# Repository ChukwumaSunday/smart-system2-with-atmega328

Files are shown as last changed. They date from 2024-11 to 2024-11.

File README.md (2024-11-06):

# smart-system2-with-atmega328
Pro-Tracking Solution Board is an ecosystem friendly onboard tracking technology and multi-functional development board based on ATMEGA328 microcontroller, designed to meet the requirements of embedded systems, vehicles/general tracking, providing a comprehensive set of features and peripherals on a single chip. 

PRO TRACKER SYSTEM
ABSTRACT:
The research is about creating a system for tracking vehicle, driver and products. Objective of the research is to design, develop and develop a GPS based
Tracking System in order to monitor and display location of vehicle on Google Maps and Other Dashboards. This system used ATMEGA328 as a microcontroller and it will be used as the main processing unit. Next, SIM7600E 4G LTE GSM/GPS module is used for network connectivity, routing the coordinate and connecting with the user.

INTRODUCTION
	Pro-Tracker Solution Board is an ecosystem friendly onboard tracking technology and multi-functional development board based on SIM7600E module that supports 4G network and  also support 2G/3G network communications, controlled by STM32 microcontroller, designed to meet the requirements of embedded systems, vehicles/general tracking, providing a comprehensive set of features and peripherals on a single board for DIY project kits. 
	The system is optimized for low power consumption and real-time processing, making it suitable for wide rand of applications.

AIM:
	To develop a multi-fuctional system that will solve the problem of location, driver and product tracking for both the military and civilians, perform driver and vehicle control, real time monitoring and ubiquitous in developing embedded systems/IoT technologies.
	To optimize the system for low power consumption and real-time processing, making it suitable for wide rand of applications.
	  To design a system that can be used in consumer products such as Vehicle Tracking System(VTS), Appliances Remote Controls, Motor Control Systems, IoT Projects, Medical devices, Gaming Console, Home Automation Systems and more.
Achievement: 
	Done with the schematic designs, board layout and ready for PCB fabrication.
Result: 
	No test carried out yet on the system as it’s still at design stage
Status of the project: 
	First stage which is PCB development is done. Therefore, the project is 40% near completion.
Conclusion:
	 All hands are on desk to ensure the project is completed as soon as possible if all the necessary system requirements are made available.

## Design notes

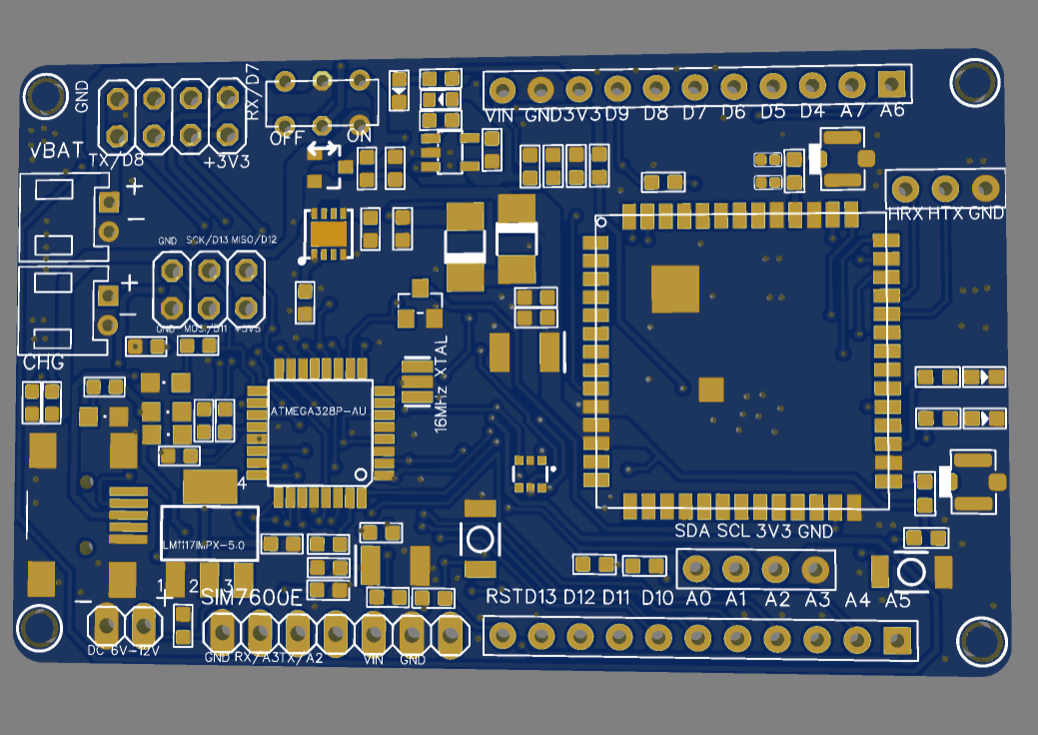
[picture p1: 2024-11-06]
Pro-Tracker(A9 ATmega328P-AU)/Front_Screenshot.png

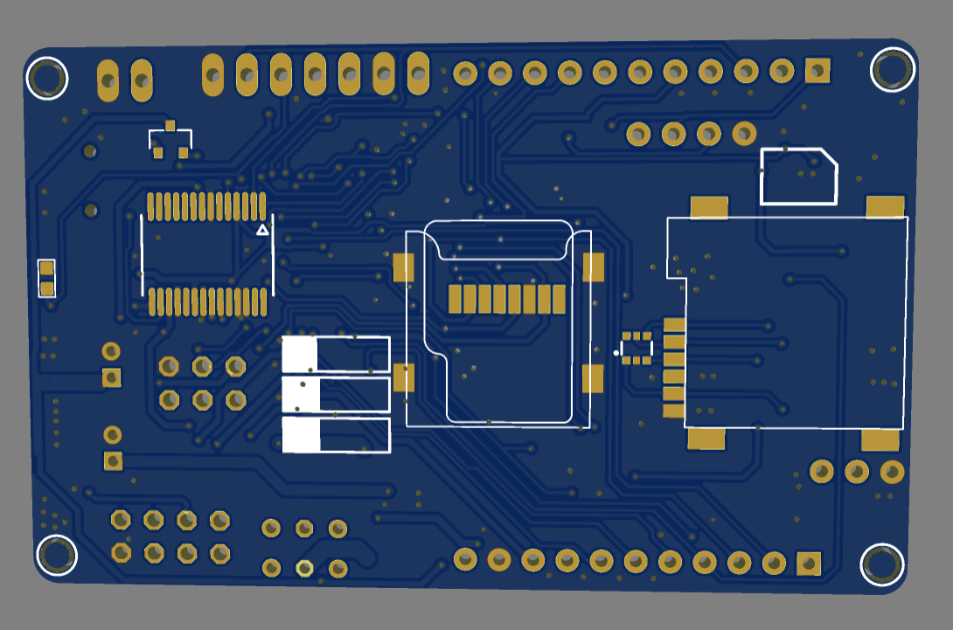
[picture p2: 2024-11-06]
Pro-Tracker(A9 ATmega328P-AU)/Back_Screenshot.png

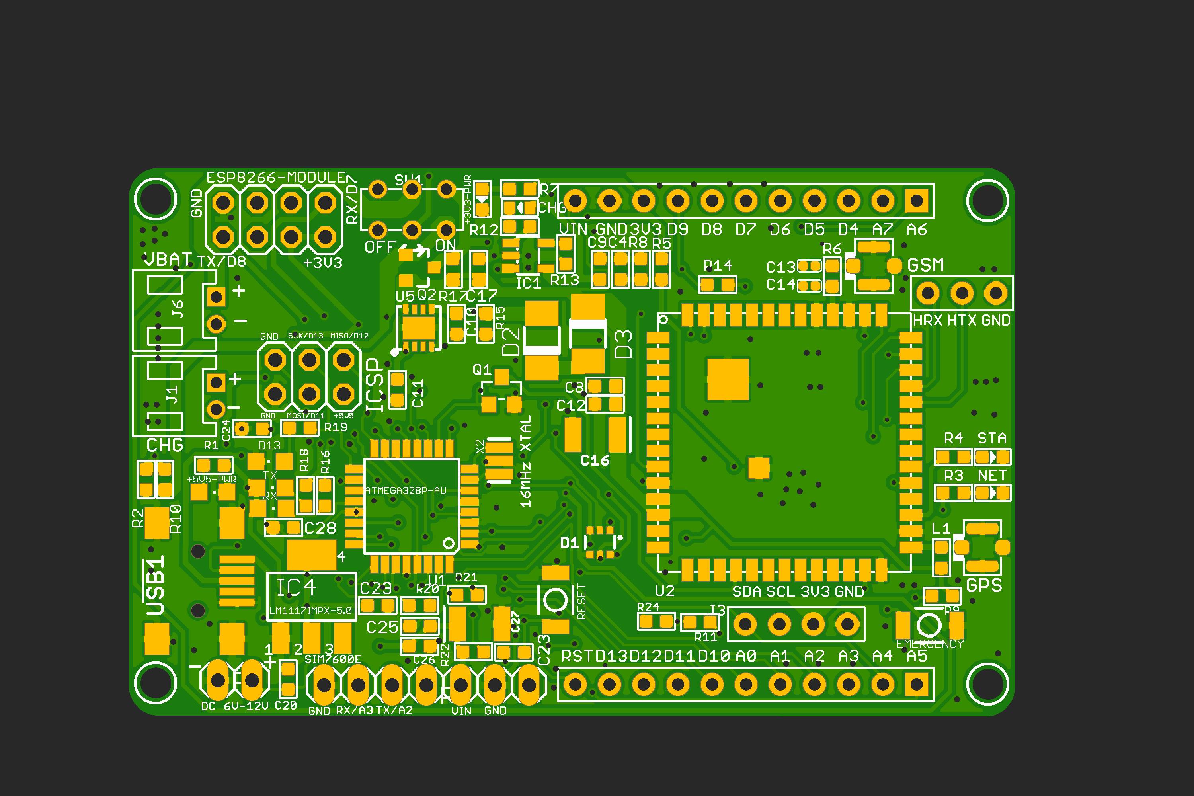
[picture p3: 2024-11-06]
Pro-Tracker(A9 ATmega328P-AU)/proto_tracks11_Top.png

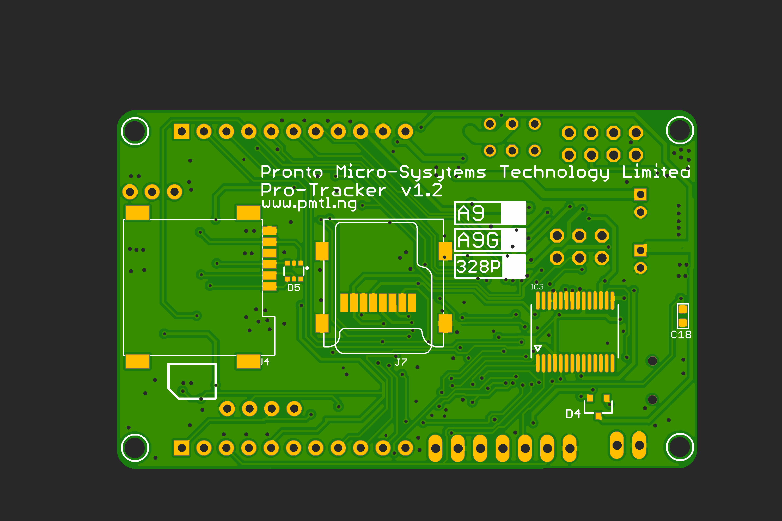
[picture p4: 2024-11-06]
Pro-Tracker(A9 ATmega328P-AU)/proto_tracks11_Bottom.png

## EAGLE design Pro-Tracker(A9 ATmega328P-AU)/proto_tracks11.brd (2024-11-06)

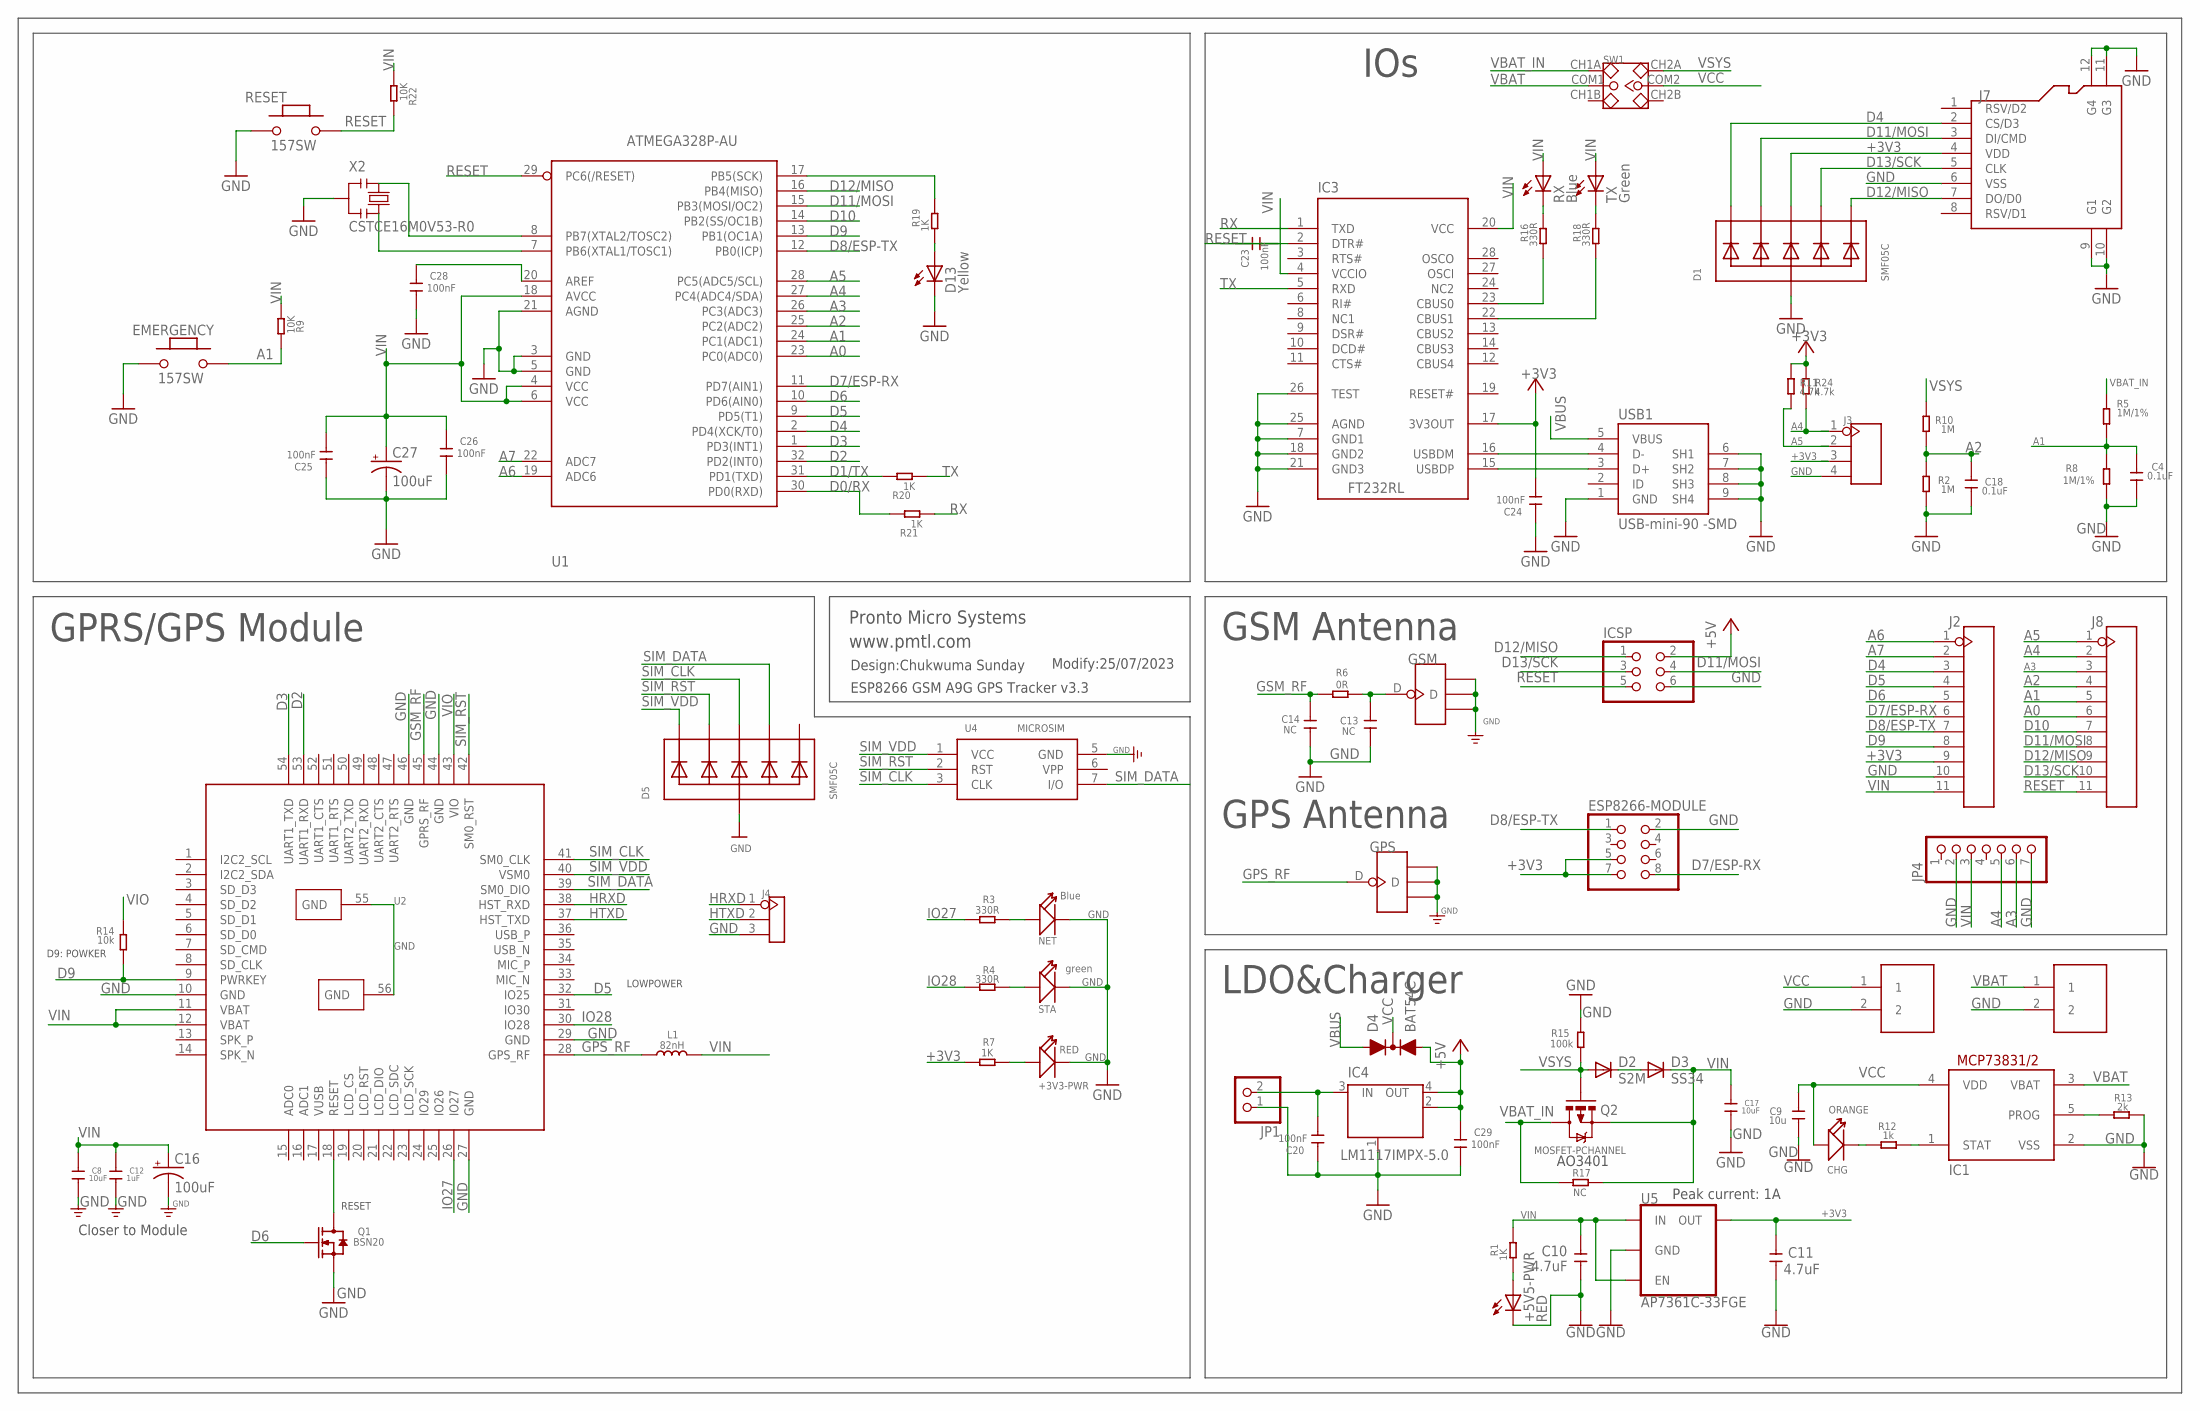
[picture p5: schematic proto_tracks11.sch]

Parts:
+3V3-PWR: RED; LED-0603
+5V5-PWR: RED; OPTO_CHIPLED_0805
C4, C18: 0.1uF; C0603
C8, C17: 10uF; C0603
C9: 10u; C0603
C10, C11: 4.7uF; C0603
C12: 1uF; C0603
C13, C14: NC; C0402
C16, C27: 100uF; EIA3528
C20, C23, C24, C25, C26, C28, C29: 100nF; C0603
CHG: ORANGE; D0603
D1, D5: SMF05C; SOT363
D2: S2M; DO-214AC
D3: SS34; DO-214AC
D4: BAT54C; SOT23-R
D13: Yellow; OPTO_CHIPLED_0805
EMERGENCY: 157SW; SWITCHES_SMD_157SW
ESP8266-MODULE: PINHD-2X4; 2X04
GPS: ANTENNA-U-FL; 4P-U-FL
GSM: ANTENNA-U-FL; 4P-U-FL
IC1: MCP73831/OT; SOT23-5L
IC3: FT232RL; INTEGRATEDCIRCUITS_SSOP28
IC4: LM1117IMPX-5.0; INTEGRATEDCIRCUITS_LINEAR_SOT223
ICSP: PINHD-2X3; 2X03
J1, J6: PH2.0-2P-90-DIP
J2, J8: HEADER-11P-2.54; 11P-2.54
J3: HEADER-4P-60/35MILROUND; 4P-65/35ROUND
J4: HEADER-3P-2.54; 3P-2.54
J7: HOLDER-MICROSD-8P; 8P-SMD
JP1: PINHD-1X2; 1X02
JP4: PINHD-1X7; 1X07
L1: 82nH; L0603
NET: Blue; LED-0603
Q1: BSN20; SOT23@1
Q2: MOSFET-PCHANNEL; SOT23-3
R1, R7, R19, R20, R21: 1K; R0603
R2, R10: 1M; R0603
R3, R4, R16, R18: 330R; R0603
R5, R8: 1M/1%; R0603
R6: 0R; R0603
R9, R22: 10K; R0603
R11, R24: 4.7k; R0603
R12: 1k; R0603
R13: 2k; R0603
R14: 10k; R0603
R15: 100k; R0603
R17: NC; R0603
RESET: 157SW; SWITCHES_SMD_157SW
RX: Blue; OPTO_CHIPLED_0805
STA: green; LED-0603
SW1: SWITCH-2CH-6P; 6P-2CH-2.54-7.6X3.0
TX: Green; OPTO_CHIPLED_0805
U1: ATMEGA328P-AU; ARDUINO-UCS&SOCS_TQFP32-08
U2: A9G
U4: MICROSIM
U5: AP7361C-33FGE; 8-UDFN
USB1: USB-mini-90 -SMD; CONNETTORI_USB-MINI-B_2
X2: CSTCE16M0V53-R0; CRISTALLI_RESONATOR

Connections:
+3V3: C11.2, C24.2, D1.4 (C3), ESP8266-MODULE.5, ESP8266-MODULE.7, IC3.17 (3V3OUT), J2.9, J3.3, J7.4 (VDD), R7.1, R11.2, R24.2, U5.1 (OUT)
+5V: C29.1, D4.2 (A2), IC4.2 (OUT), IC4.4 (OUT), ICSP.2
A0: J8.6, U1.23 (PC0(ADC0))
A1: C4.1, EMERGENCY.2, J8.5, R5.1, R8.2, R9.2, U1.24 (PC1(ADC1))
A2: C18.1, J8.4, R2.2, R10.1, U1.25 (PC2(ADC2))
A3: J8.3, JP4.6, U1.26 (PC3(ADC3))
A4: J3.1, J8.2, JP4.5, R24.1, U1.27 (PC4(ADC4/SDA))
A5: J3.2, J8.1, R11.1, U1.28 (PC5(ADC5/SCL))
A6: J2.1, U1.19 (ADC6)
A7: J2.2, U1.22 (ADC7)
D0/RX: R21.2, U1.30 (PD0(RXD))
D1/TX: R20.2, U1.31 (PD1(TXD))
D2: U1.32 (PD2(INT0)), U2.53 (UART1_RXD)
D3: U1.1 (PD3(INT1)), U2.54 (UART1_TXD)
D4: D1.1 (C1), J2.3, J7.2 (CS/D3), U1.2 (PD4(XCK/T0))
D5: J2.4, U1.9 (PD5(T1)), U2.32 (IO25)
D6: J2.5, Q1.1 (G), U1.10 (PD6(AIN0))
D7/ESP-RX: ESP8266-MODULE.8, J2.6, U1.11 (PD7(AIN1))
D8/ESP-TX: ESP8266-MODULE.1, J2.7, U1.12 (PB0(ICP))
D9: J2.8, R14.1, U1.13 (PB1(OC1A)), U2.9 (PWRKEY)
D10: J8.7, U1.14 (PB2(SS/OC1B))
D11/MOSI: D1.3 (C2), ICSP.4, J7.3 (DI/CMD), J8.8, U1.15 (PB3(MOSI/OC2))
D12/MISO: D1.6 (C5), ICSP.1, J7.7 (DO/D0), J8.9, U1.16 (PB4(MISO))
D13/SCK: D1.5 (C4), ICSP.3, J7.5 (CLK), J8.10, R19.2, U1.17 (PB5(SCK))
GND: +3V3-PWR.-, +5V5-PWR.C, C4.2, C8.1, C9.1, C10.1, C11.1, C12.1, C13.1, C14.1, C16.C (-), C17.1, C18.2, C20.1, C24.1, C25.1, C26.2, C27.C (-), C28.2, C29.2, D1.2 (A), D5.2 (A), D13.C, EMERGENCY.1, ESP8266-MODULE.2, GPS.GND1, GPS.GND2, GPS.GND3, GSM.GND1, GSM.GND2, GSM.GND3, IC1.2 (VSS), IC3.7 (GND1), IC3.18 (GND2), IC3.21 (GND3), IC3.25 (AGND), IC3.26 (TEST), IC4.1 (GND/ADJ), ICSP.6, J1.2, J2.10, J3.4, J4.3, J6.2, J7.6 (VSS), J7.9 (G1), J7.10 (G2), J7.11 (G3), J7.12 (G4), JP1.1, JP4.2, JP4.7, NET.-, Q1.2 (S), R2.1, R8.1, R13.2, R15.2, RESET.1, STA.-, U1.3 (GND), U1.5 (GND), U1.21 (AGND), U2.10 (GND), U2.27 (GND), U2.29 (GND), U2.44 (GND), U2.46 (GND), U2.55 (GND), U2.56 (GND), U4.5 (GND), U5.4 (GND), U5.EP (GND), USB1.1 (GND), USB1.6 (SH1), USB1.7 (SH2), USB1.8 (SH3), USB1.9 (SH4), X2.2
GPS_RF: GPS.D, L1.1, U2.28 (GPS_RF)
GSM_RF: C14.2, R6.1, U2.45 (GPRS_RF)
HRXD: J4.1, U2.38 (HST_RXD)
HTXD: J4.2, U2.37 (HST_TXD)
IO27: R3.1, U2.26 (IO27)
IO28: R4.1, U2.30 (IO28)
unnamed: R4.2, STA.+
unnamed: D2.C, D3.A
unnamed: +3V3-PWR.+, R7.2
unnamed: C28.1, U1.20 (AREF)
unnamed: +5V5-PWR.A, R1.1
unnamed: C20.2, IC4.3 (IN), JP1.2
unnamed: NET.+, R3.2
unnamed: Q1.3 (D), U2.18 (RESET)
unnamed: C23.2, IC3.2 (DTR#)
unnamed: R16.2, RX.C
unnamed: R18.2, TX.C
unnamed: IC3.23 (CBUS0), R16.1
unnamed: IC3.22 (CBUS1), R18.1
unnamed: IC3.15 (USBDP), USB1.3 (D+)
unnamed: IC3.16 (USBDM), USB1.4 (D-)
unnamed: D13.A, R19.1
unnamed: CHG.-, R12.1
unnamed: IC1.1 (STAT), R12.2
unnamed: IC1.5 (PROG), R13.1
unnamed: U1.7 (PB6(XTAL1/TOSC1)), X2.3
unnamed: U1.8 (PB7(XTAL2/TOSC2)), X2.1
unnamed: C13.2, GSM.D, R6.2
RESET: C23.1, ICSP.5, J8.11, R22.2, RESET.2, U1.29 (PC6(/RESET))
RX: IC3.1 (TXD), R21.1
SIM_CLK: D5.4 (C3), U2.41 (SM0_CLK), U4.3 (CLK)
SIM_DATA: D5.5 (C4), U2.39 (SM0_DIO), U4.7 (I/O)
SIM_RST: D5.3 (C2), U2.42 (SM0_RST), U4.2 (RST)
SIM_VDD: D5.1 (C1), U2.40 (VSM0), U4.1 (VCC)
TX: IC3.5 (RXD), R20.1
VBAT: IC1.3 (VBAT), J6.1, SW1.COM1
VBAT_IN: Q2.3 (D), R5.2, R17.1, SW1.CH1A
VBUS: D4.1 (A1), USB1.5 (VBUS)
VCC: C9.2, CHG.+, D4.3 (C), IC1.4 (VDD), J1.1, SW1.COM2
VIN: C8.2, C10.2, C12.2, C16.A (+), C17.2, C25.2, C26.1, C27.A (+), D3.C, IC3.4 (VCCIO), IC3.20 (VCC), J2.11, JP4.3, L1.2, Q2.2 (S), R1.2, R9.1, R17.2, R22.1, RX.A, TX.A, U1.4 (VCC), U1.6 (VCC), U1.18 (AVCC), U2.11 (VBAT), U2.12 (VBAT), U5.5 (EN), U5.8 (IN)
VIO: R14.2, U2.43 (VIO)
VSYS: D2.A, Q2.1 (G), R10.2, R15.1, SW1.CH2A

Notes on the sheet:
GSM Antenna
GPRS/GPS Module
LOWPOWER
RESET
D9: POWKER
Peak current: 1A
www.pmtl.com
IOs
LDO&Charger
GPS Antenna
Design:Chukwuma Sunday
Modify:25/07/2023
Pronto Micro Systems
Closer to Module
AO3401
ESP8266 GSM A9G GPS Tracker v3.3

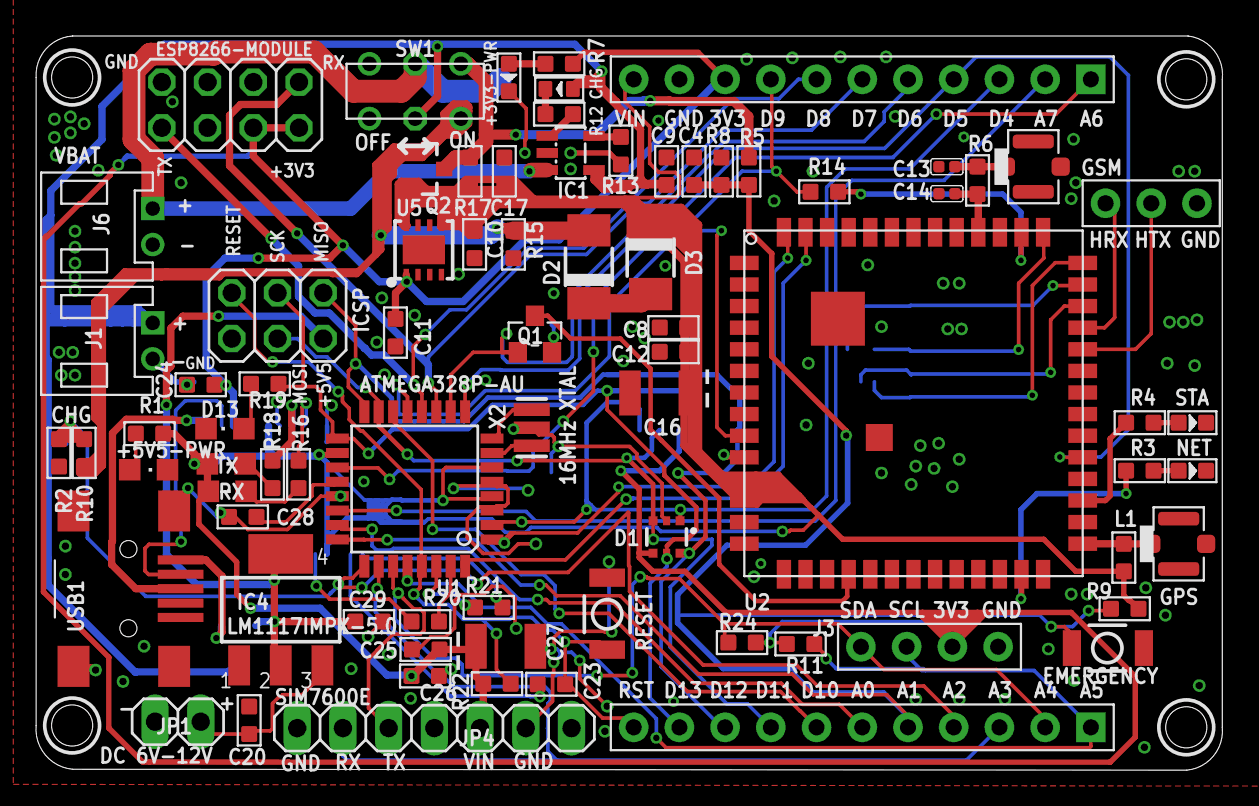
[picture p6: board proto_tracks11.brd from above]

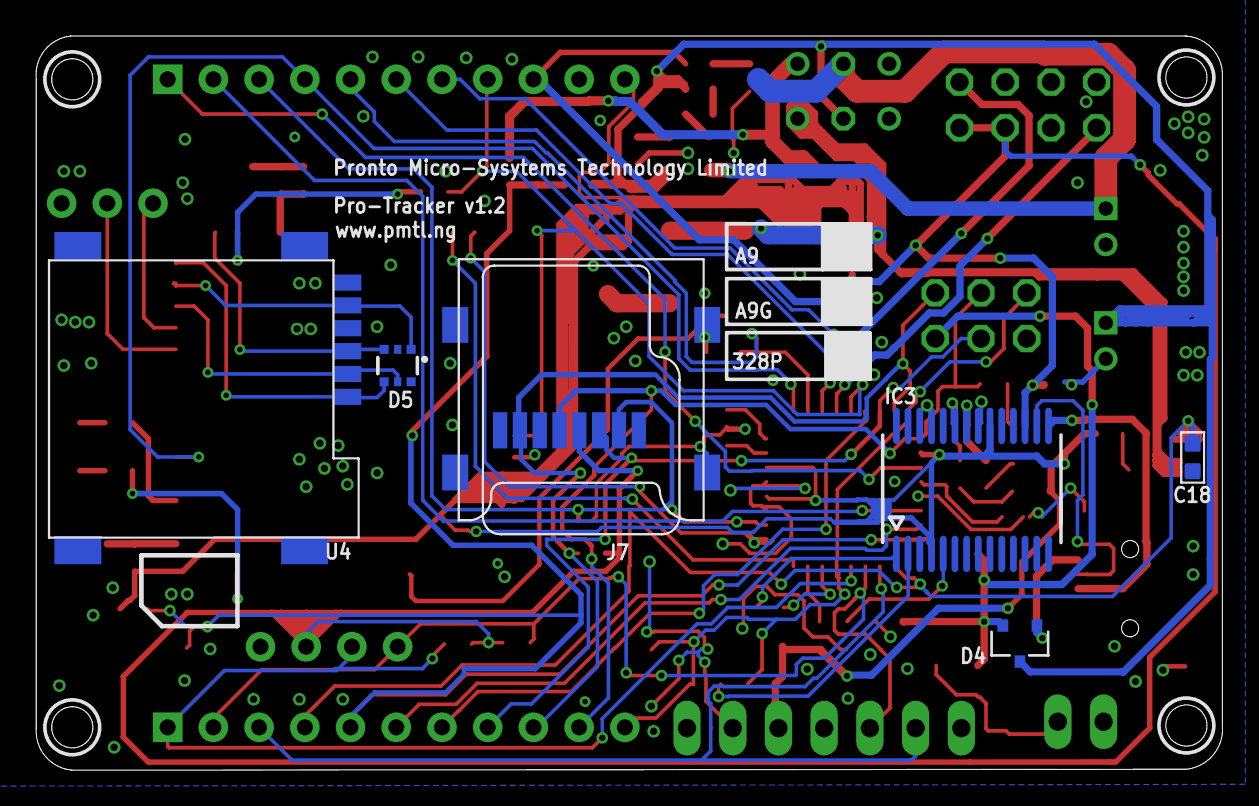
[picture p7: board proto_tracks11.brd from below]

Board: 2 copper layers, 65.9 x 40.8 mm, 83 parts (6 on the bottom side), 67 nets.

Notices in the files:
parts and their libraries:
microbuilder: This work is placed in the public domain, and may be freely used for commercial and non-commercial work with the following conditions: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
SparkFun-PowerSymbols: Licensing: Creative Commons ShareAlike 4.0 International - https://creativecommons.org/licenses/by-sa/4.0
